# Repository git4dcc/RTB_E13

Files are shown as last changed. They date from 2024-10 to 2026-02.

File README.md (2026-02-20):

# RTB_E13




This E13 module implements a 12 channel WS2811 emulator with compatible bus timing to drive multiplex (charlieplexing) LEDs. The E13 may be cascaded with regular WS28xx chips. The number of LEDs attached is automatically detected (0-12). This module allows the common LED voltage be dynamically adjusted via the bus protocol. The intended use is to drive Multiplex Signals on Model Railway layouts via the WS28xx bus.

_Note: The RTB_E13 is nearly identical to the [RTB_E15](/../../../../git4dcc/RTB_E15) but allows for variable LED voltage._

<details>
<summary>See also</summary>

- [RTB_E10](/../../../../git4dcc/RTB_E10)
- [RTB_E15](/../../../../git4dcc/RTB_E15)

</details>

<details>
<summary>User Guides</summary>

- [User Guide - DE](https://rtb4dcc.de/ws2811_guide_de/)
- User Guide - EN

</details>

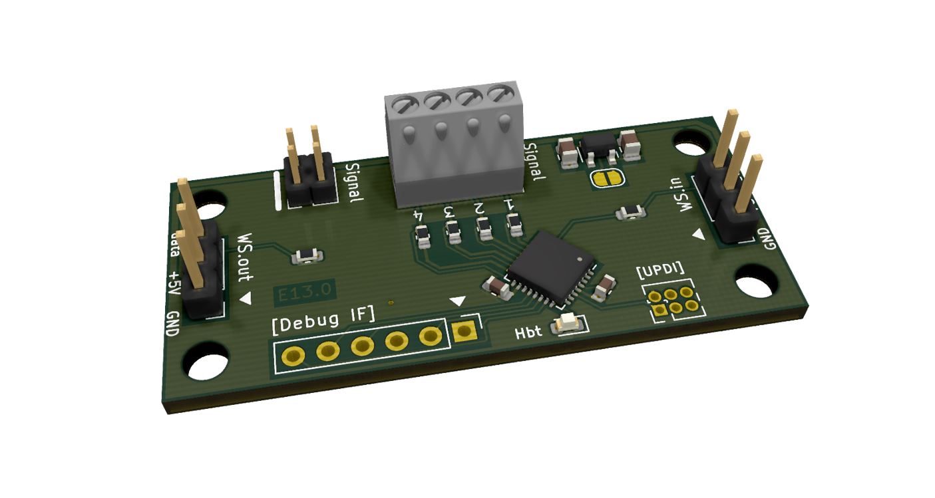
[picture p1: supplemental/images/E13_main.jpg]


The decoder has the following features,
- **Protocol**
  - WS2811 compatible timing
- **LED ports**
  - 12 channel output
  - Charlieplexing (Multiplexing) output
  - 128 step PWM (300Hz)
  - Software adjustable LED voltage 0..5V (see also [RTB_E15](/../../../../git4dcc/RTB_E15))
  - gamma correction (optional)
- firmware update via V24 debug interface

# Hardware
My current PCB layout uses SMD footprints with 0.5mm pitch and 0603 parts. Reflow soldering is my recommendation, but with some experience handsoldering is also possible.

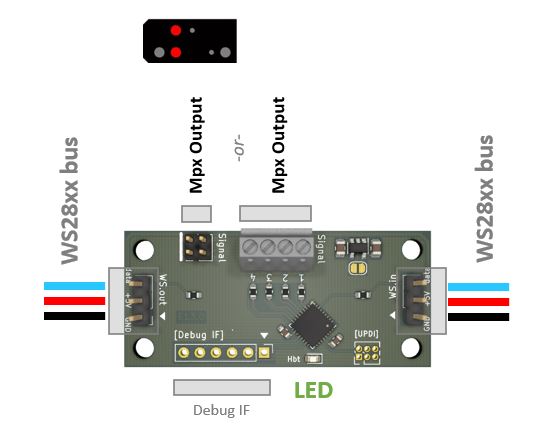
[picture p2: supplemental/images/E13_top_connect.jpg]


## PCB
- 2-layer PCB, FR4, 1.6mm
- CPU: AVR64DB32
- BUS: WS28xx
- LED: Charlieplexing

## Kicad
[Schematic](doc/E13_schematic.pdf) | [Layout](doc/E13_layout.pdf) | [Gerber](gerber)

<details>
<summary>Dependency</summary>
<br>
  
:yellow_circle: Requires my Kicad project library [RTB_SamacSys](/../../../../git4dcc/RTB_SamacSys) in the same directory tree.

</details>

## Firmware
Filename structure: { **pcb** }{ **code** }{ **version** }.hex

Example: **E13F0001**.hex

| | Description |
| --- | --- |
| **pcb** | Name of matching hardware (**E13**) |
| **code** | Type of code contained (**R**=rom, **B**=bootloader, **F**=flash, **U**=bld update, **P**=UPDI factory code) |
| **version** | Release version (**####**) |

## UPDI
The fuse settings as well as the P-code (E13Pxxxx.hex) has to be installed by using UPDI.<br>

<details>
<summary>Details</summary>

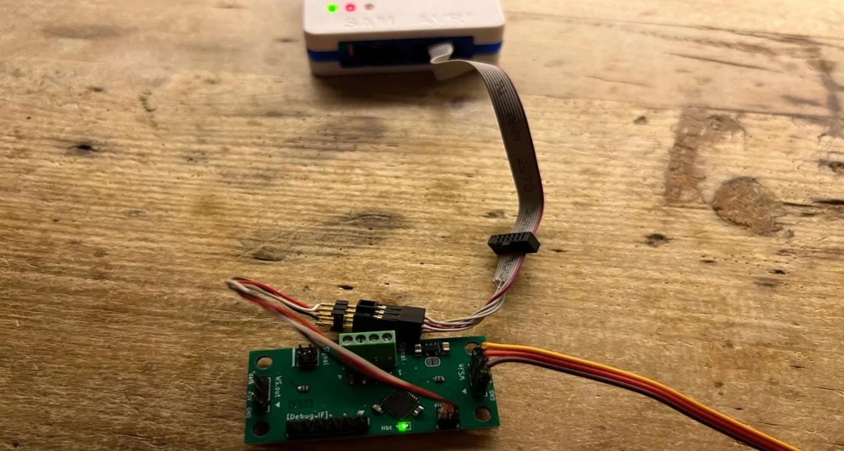
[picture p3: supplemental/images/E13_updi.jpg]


| Fuse Setting | P-code Install |
| --- | --- |
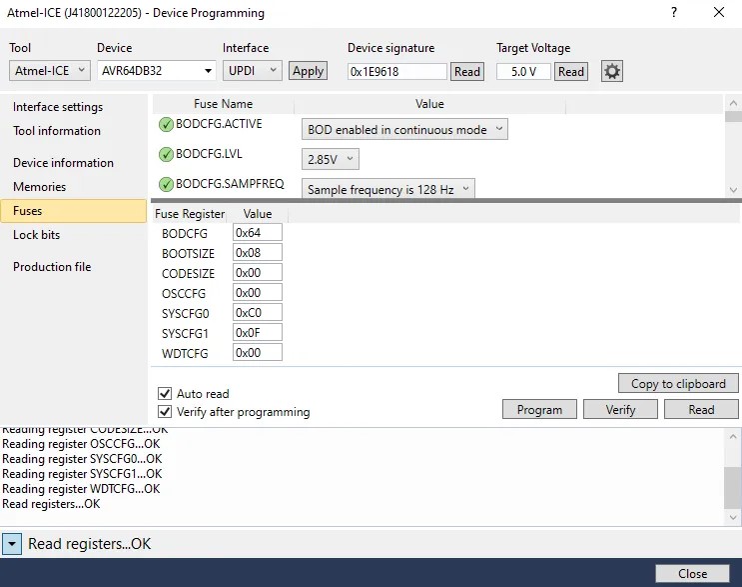
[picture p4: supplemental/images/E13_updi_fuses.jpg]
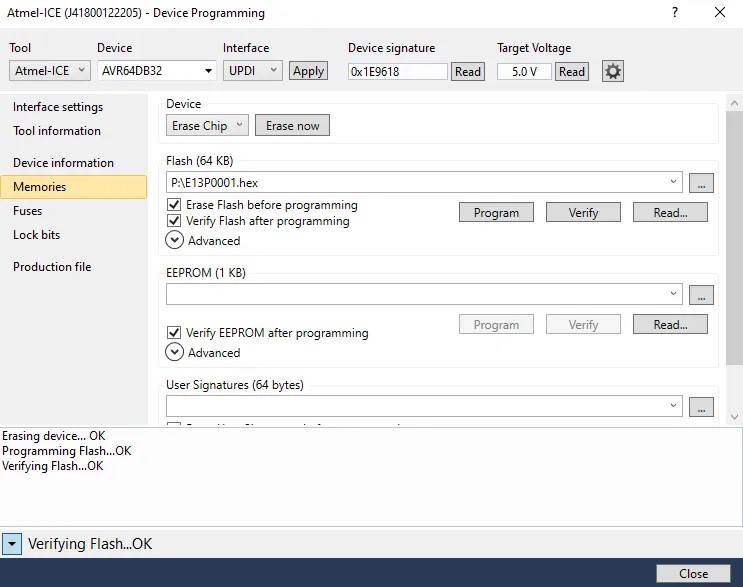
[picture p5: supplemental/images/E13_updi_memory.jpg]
|||

</details>

## Debug Interface
Subsequent code updates can be done via the built-in serial debug interface.<br>

<details>
<summary>Details</summary>

- connect the serial cable **(1Mb, 8N1, RTS/CTS)**
- press 'break' within the VT100 terminal to bump the module to console prompt
- upload the firmware file (E13Fxxxx.hex)
- for more details, refer to the 'User Guide'

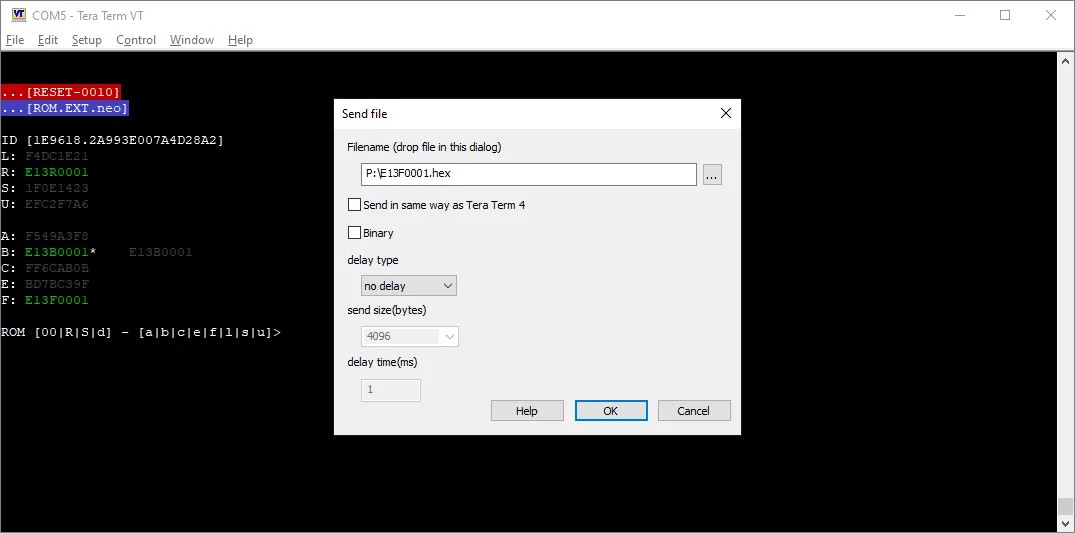
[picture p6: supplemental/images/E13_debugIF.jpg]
  

</details>

# Software
The LED common voltage must be sent as the first byte (virtual LED) over the bus followed by the intensity values for the individual LEDs, with N being the number of configured LEDs.
```
Byte order:     {voltage} {led_0} ... {led_N}
Led Voltage:    5V * {voltage} / 255
```

# Images
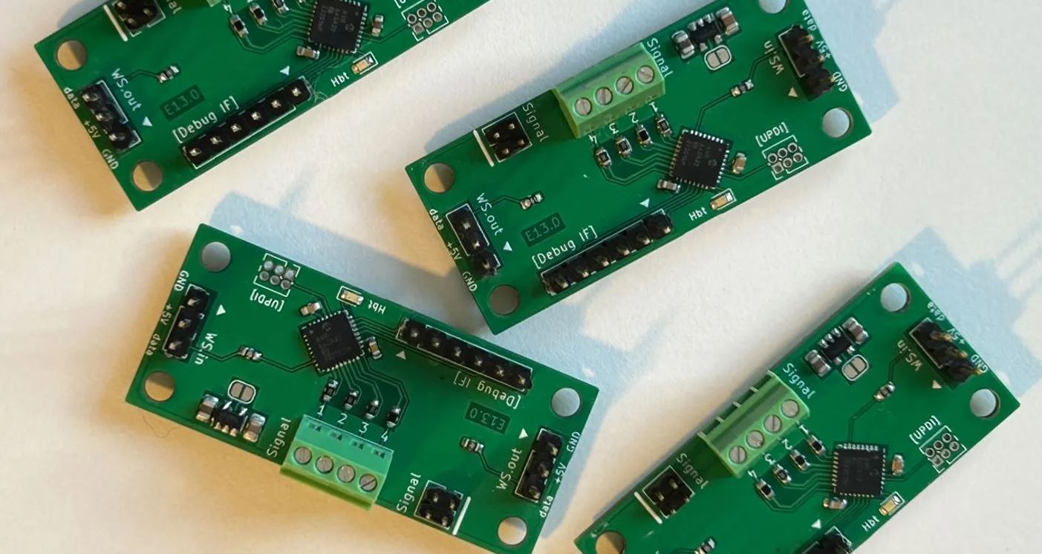
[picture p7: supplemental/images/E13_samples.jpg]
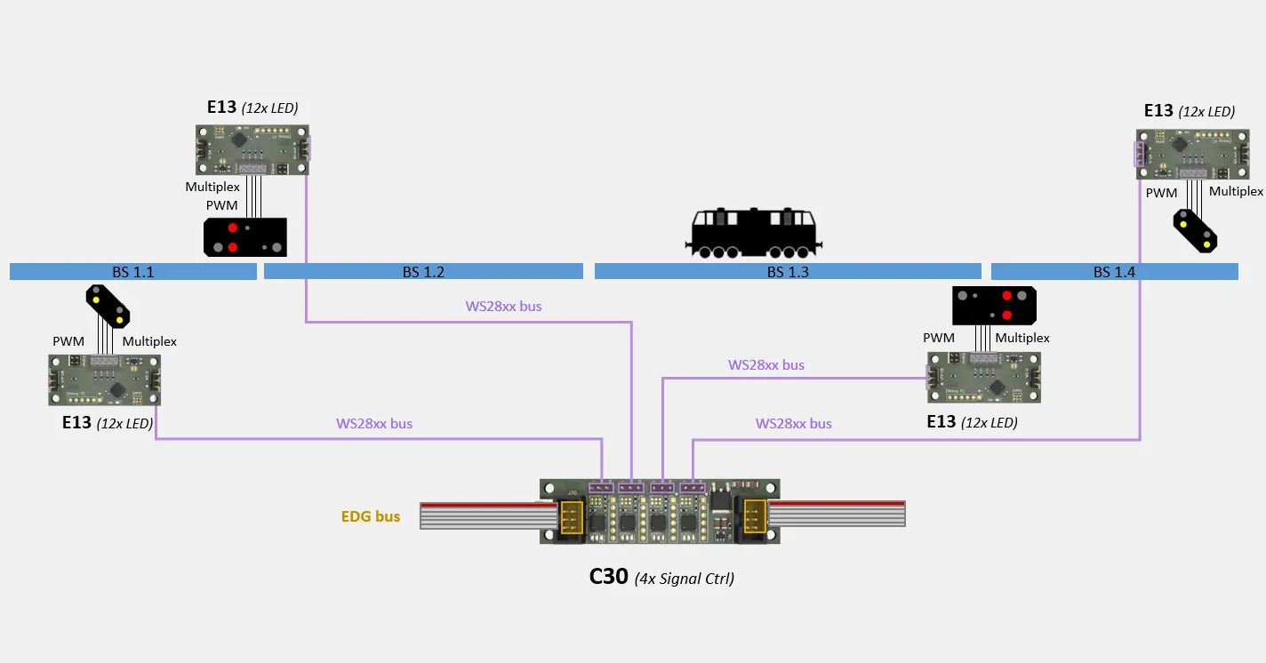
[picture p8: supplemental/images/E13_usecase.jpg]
 

This project is intended for hobby use only and is distributed in accordance with the Apache License 2.0 agreement.

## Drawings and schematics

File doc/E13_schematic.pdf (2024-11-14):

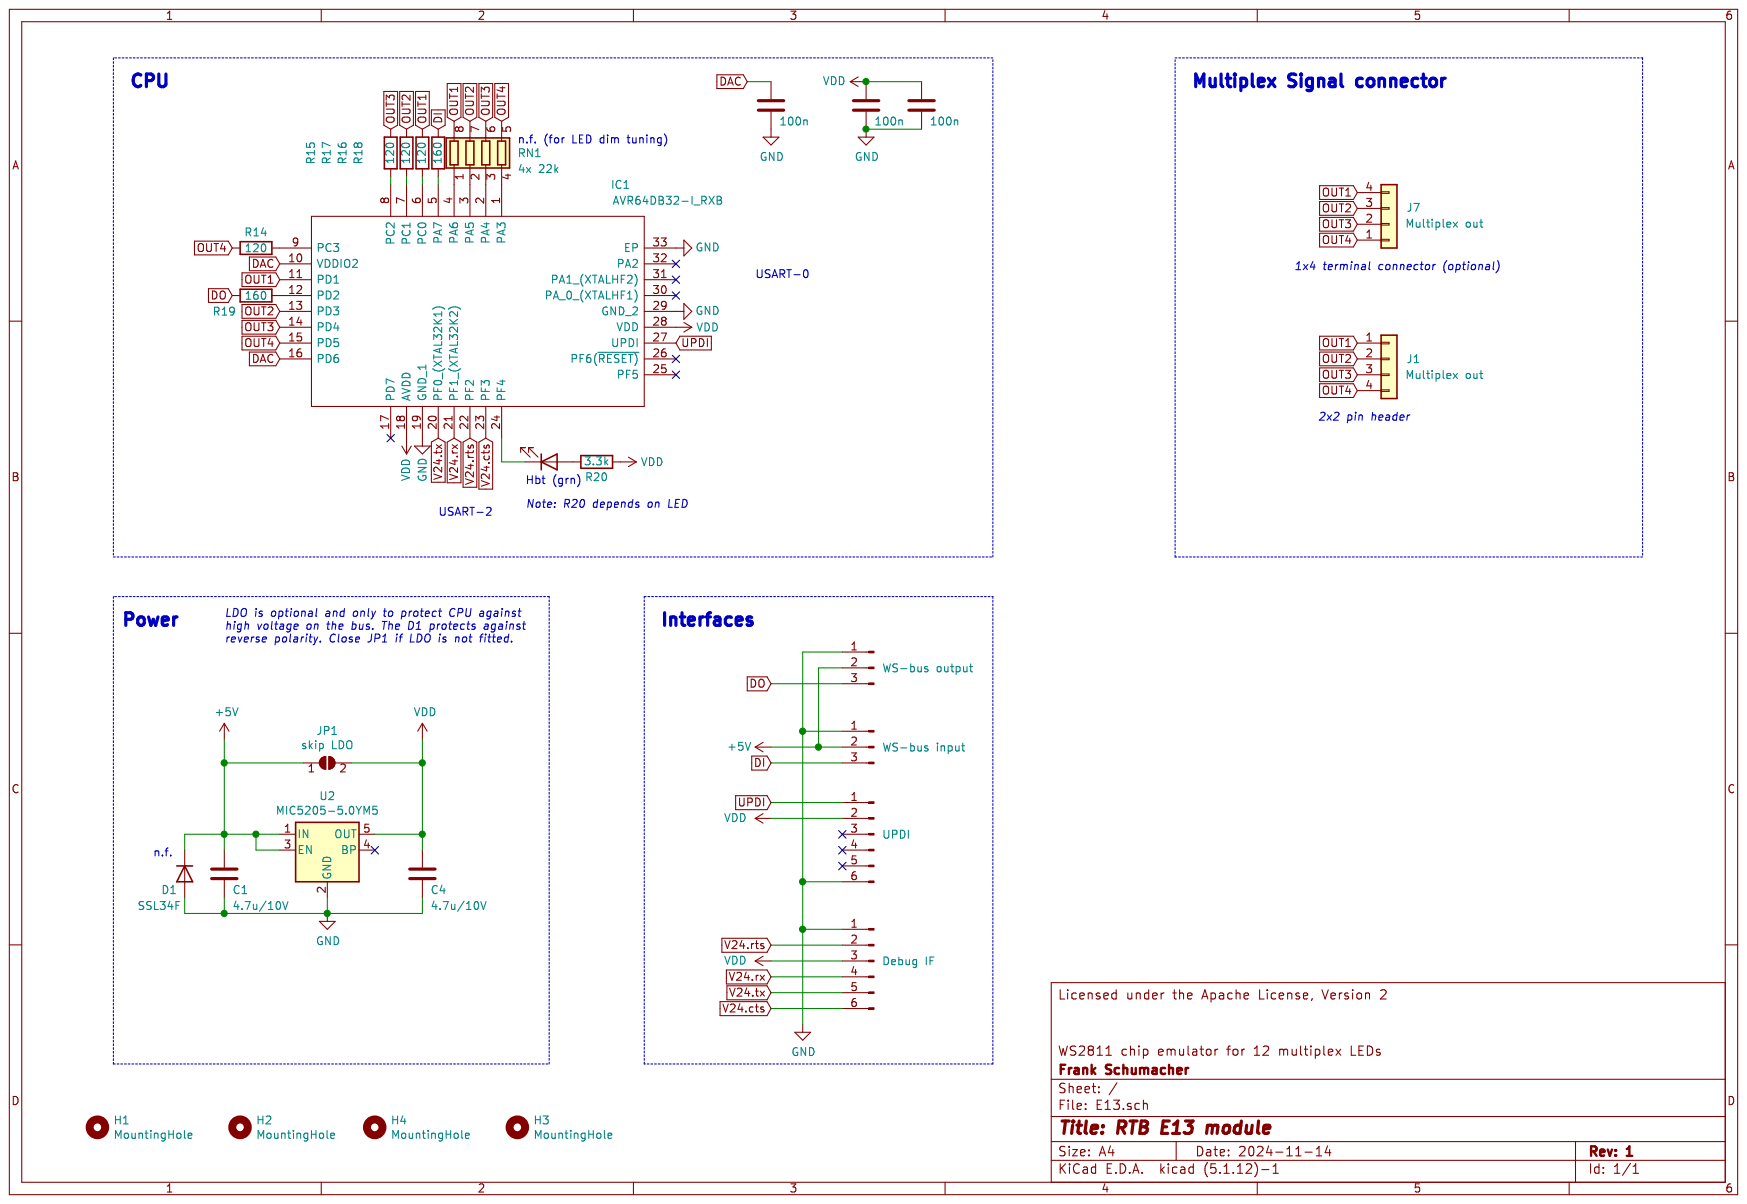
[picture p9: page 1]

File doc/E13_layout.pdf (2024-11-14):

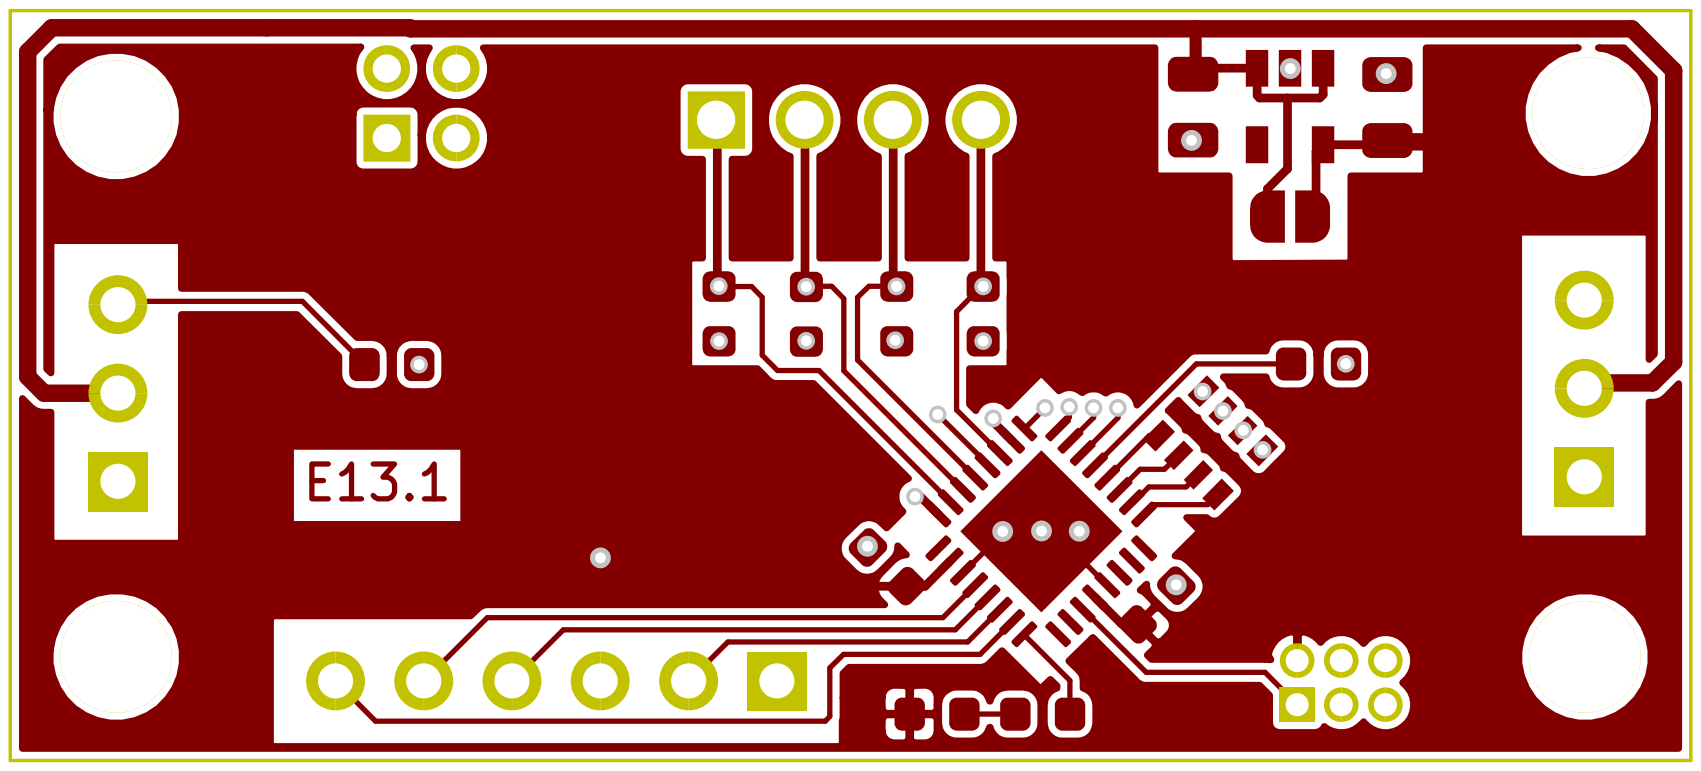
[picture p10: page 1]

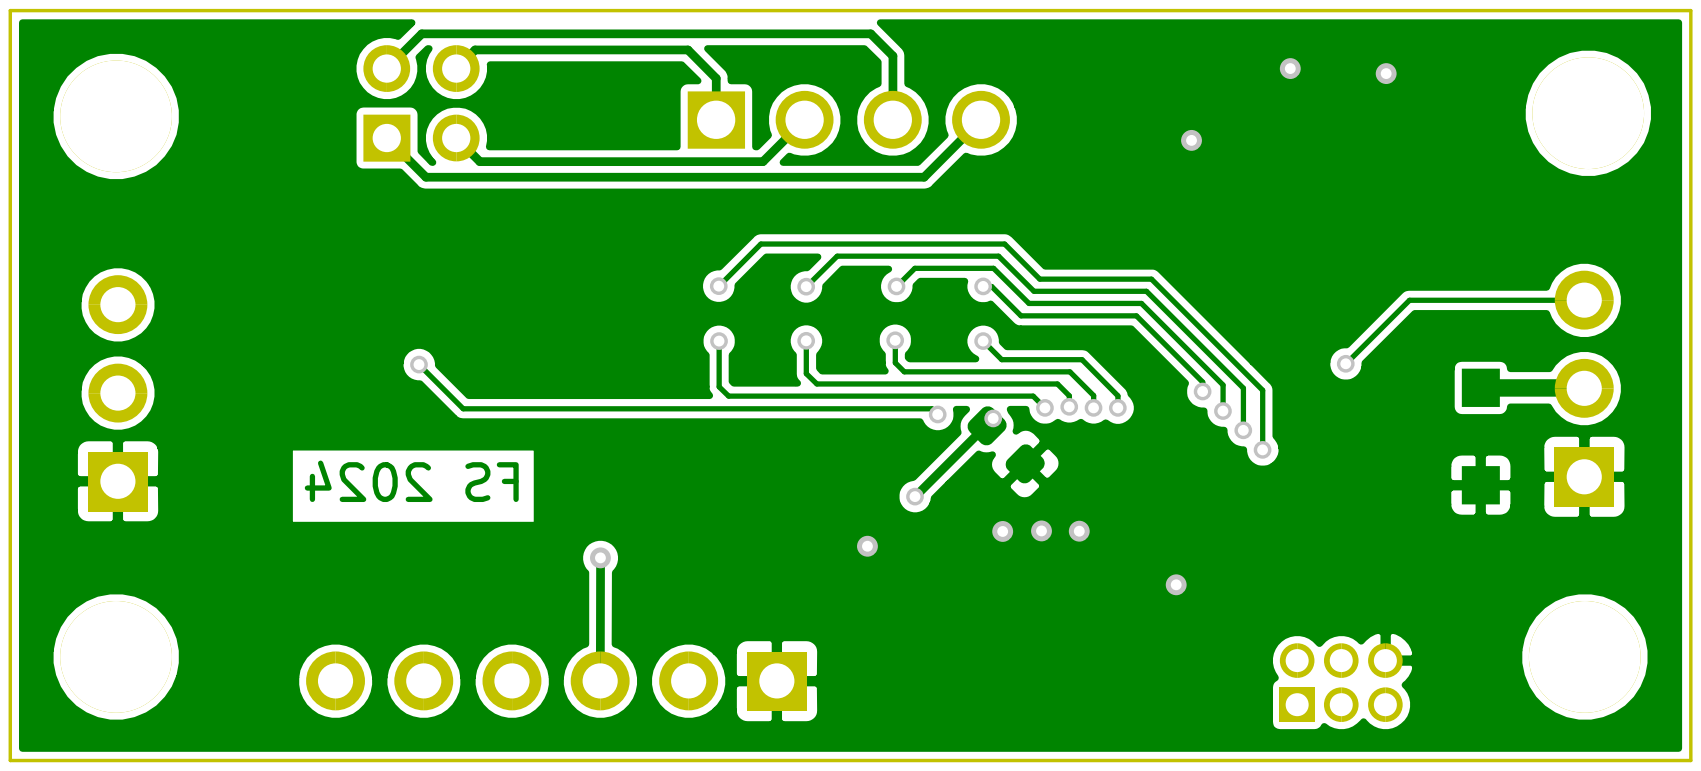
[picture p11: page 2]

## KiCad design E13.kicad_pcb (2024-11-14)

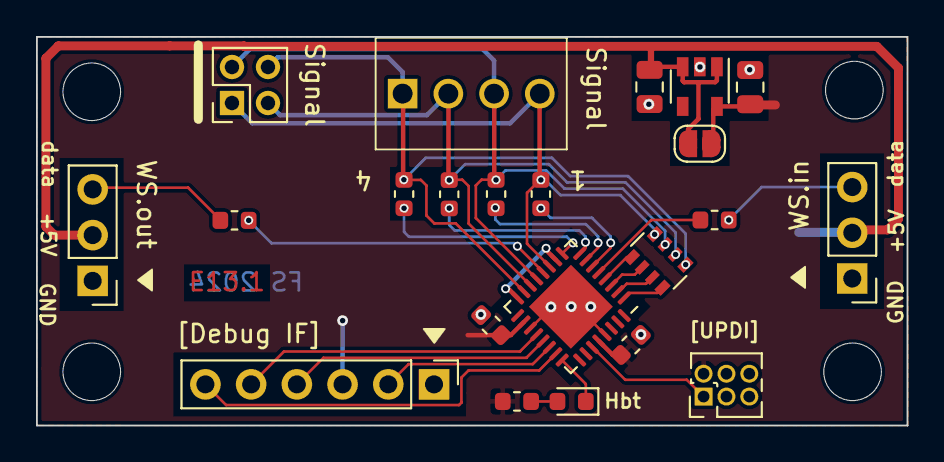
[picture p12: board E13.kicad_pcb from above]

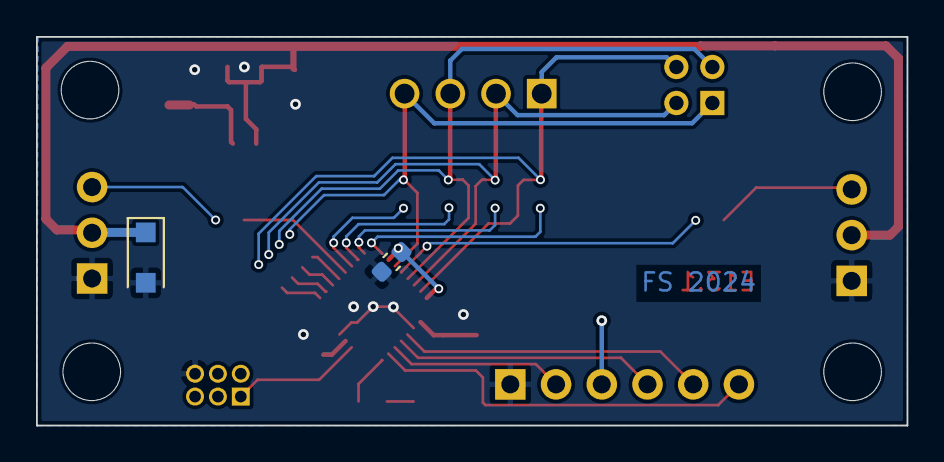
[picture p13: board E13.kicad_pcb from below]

Board: 2 copper layers, 48.4 x 21.6 mm, 28 parts (2 on the bottom side), 27 nets.

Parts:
C1, C4: 4.7u/10V; C_0805_2012Metric
C2, C3, C5: 100n; C_0603_1608Metric
D1: SSL34F; D_SOD-123F
D2: HBT(green); LED_0603_1608Metric
H1, H2, H3, H4: MountingHole; MountingHole_3.2mm_M3_DIN965
IC1: AVR64DB32-I_RXB; QFN-32-1EP_5x5mm_P0.5mm_EP3.3x3.3mm
J1: Multiplex out; PinHeader_2x02_P2.00mm_Vertical
J2: WS-bus output; PinHeader_1x03_P2.54mm_Vertical
J3: WS-bus input; PinHeader_1x03_P2.54mm_Vertical
J4: UPDI; PinHeader_2x03_P1.27mm_Vertical
J5: Debug IF; PinHeader_1x06_P2.54mm_Vertical
J7: Multiplex out; 1725672
JP1: skip LDO; SolderJumper-2_P1.3mm_Open_RoundedPad1.0x1.5mm
R14, R15, R16, R17: 120; R_0603_1608Metric
R18, R19: 160; R_0603_1608Metric
R20: 3.3k; R_0603_1608Metric
RN1: 4x 22k; R_Array_Convex_4x0603
U2: MIC5205-5.0YM5; SOT-23-5

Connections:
+5V: C1.1, D1.1, J2.2, J3.2, JP1.1, U2.1, U2.3
DAC: C5.1, IC1.10, IC1.16
DI: J3.3, R18.2
DO: J2.3, R19.2
GND: C1.2, C2.2, C3.2, C4.2, C5.2, D1.2, IC1.19, IC1.29, IC1.33, J2.1, J3.1, J4.6, J5.1, U2.2
unnamed: D2.1, IC1.24
unnamed: D2.2, R20.1
unnamed: IC1.1, RN1.4
unnamed: IC1.2, RN1.3
unnamed: IC1.3, RN1.2
unnamed: IC1.4, RN1.1
unnamed: IC1.5, R18.1
unnamed: IC1.6, R16.1
unnamed: IC1.7, R17.1
unnamed: IC1.8, R15.1
unnamed: IC1.9, R14.1
unnamed: IC1.12, R19.1
OUT1: IC1.11, J1.1, J7.4, R16.2, RN1.8
OUT2: IC1.13, J1.2, J7.3, R17.2, RN1.7
OUT3: IC1.14, J1.3, J7.2, R15.2, RN1.6
OUT4: IC1.15, J1.4, J7.1, R14.2, RN1.5
UPDI: IC1.27, J4.1
V24.cts: IC1.23, J5.6
V24.rts: IC1.22, J5.2
V24.rx: IC1.21, J5.4
V24.tx: IC1.20, J5.5
VDD: C2.1, C3.1, C4.1, IC1.18, IC1.28, J4.2, J5.3, JP1.2, R20.2, U2.5

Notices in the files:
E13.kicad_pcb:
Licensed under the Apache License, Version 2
